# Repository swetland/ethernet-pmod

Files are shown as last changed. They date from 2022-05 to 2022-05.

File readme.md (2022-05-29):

# Ethernet PMOD v2

This PCB is a PMOD (FPGA development board peripheral module) for the
Microchip LAN8720A PHY, to enable 10/100M Ethernet connectivity.

It is configured to accept the necessary 50MHz clock from the FPGA, and
exchanges data using the [RMII standard](https://en.wikipedia.org/wiki/Media-independent_interface#RMII).  A secondary header provides access
to the MDIO/MDC lines to allow access to the management interface.

I have manufactured 10 of these using JLCPCB's PCB fabrication and assembly
service (manually soldering the two throw-hole components myself) and have
used this PMOD successfully with Litex / LiteETH / VexRiscv on a Muse Lab
iCE Sugar Pro FPGA board.

This project is licensed under the [CERN OHL P v2](CERN-OHL-P-v2.txt) Permissive Open Hardware License.

## Design Files and Resources

Original design files are here: [kicad/](kicad/)

Schematic in PDF format here: [export/ethernet-pmod-v2-schematic.pdf](export/ethernet-pmod-v2-schematic.pdf)

Gerbers and CSV files used for a successful JLCPCB order, under [export/jlcpcb/](export/jlcpcb/)

Documentation on the Microchip LAN8720A: https://www.microchip.com/en-us/product/LAN8720A

## Pictures

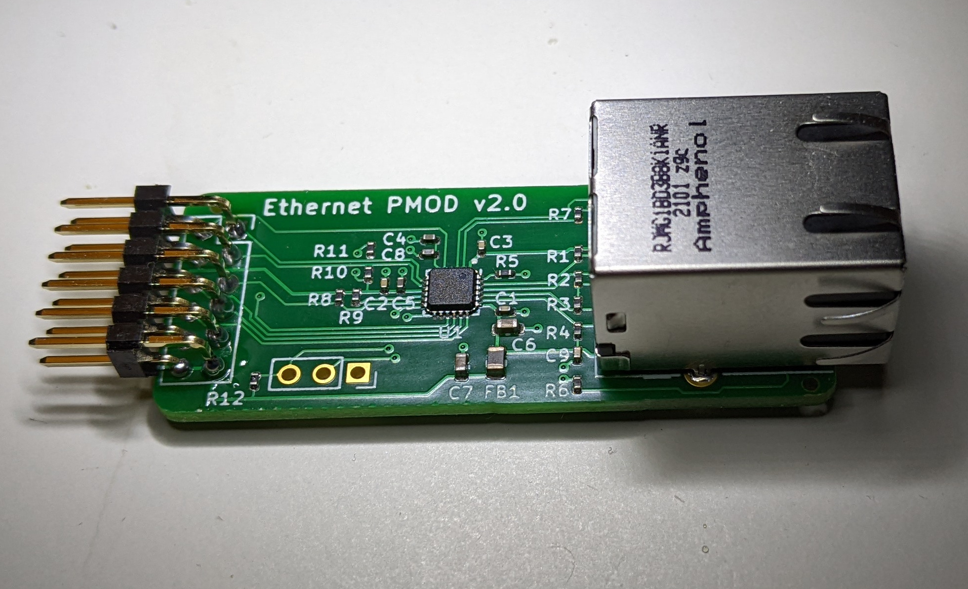
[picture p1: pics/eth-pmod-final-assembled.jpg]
final assembled pmod


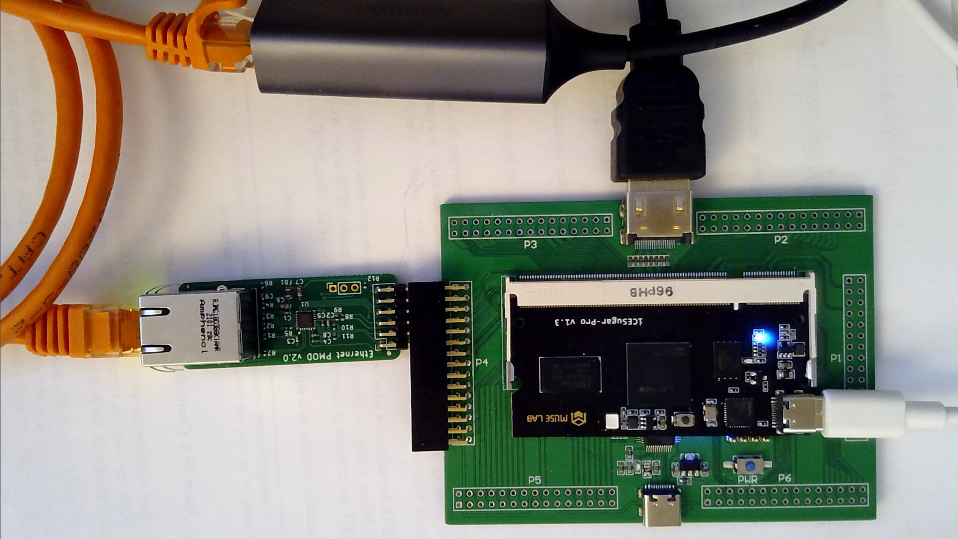
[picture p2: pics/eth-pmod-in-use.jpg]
pmod in use


## PMOD Connector Layout

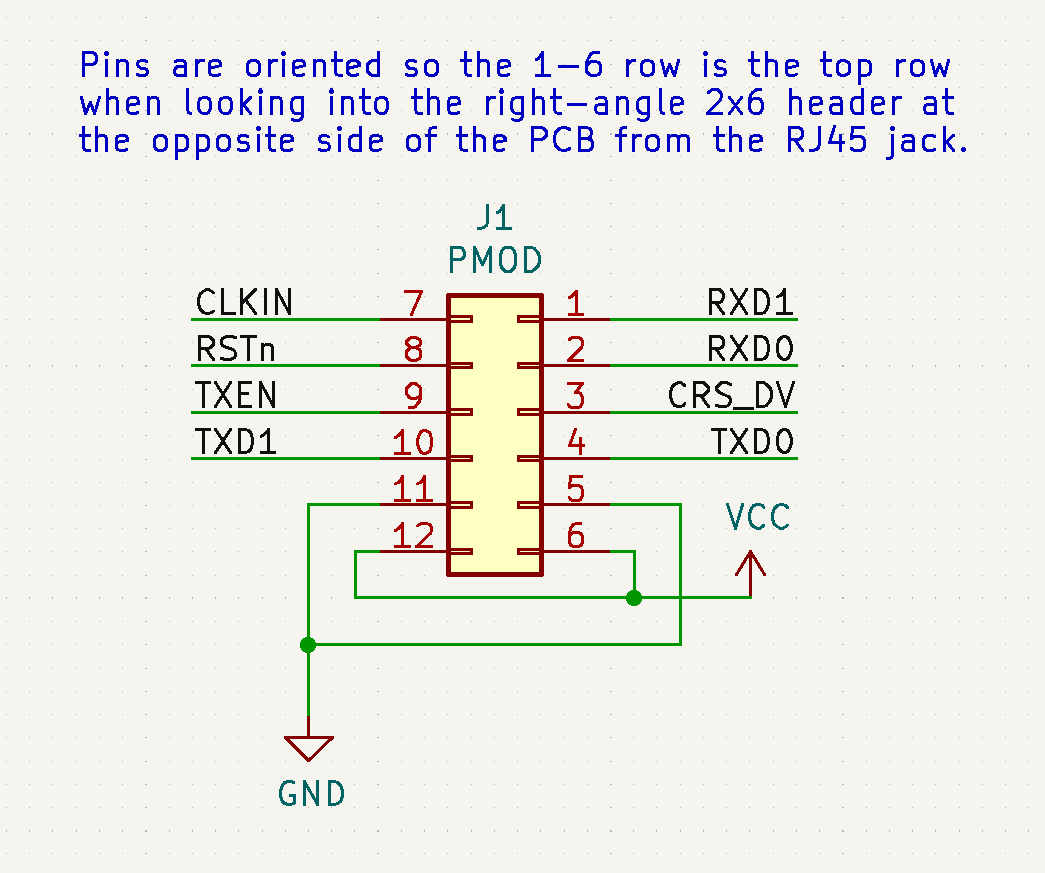
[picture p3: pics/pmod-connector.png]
pmod connector


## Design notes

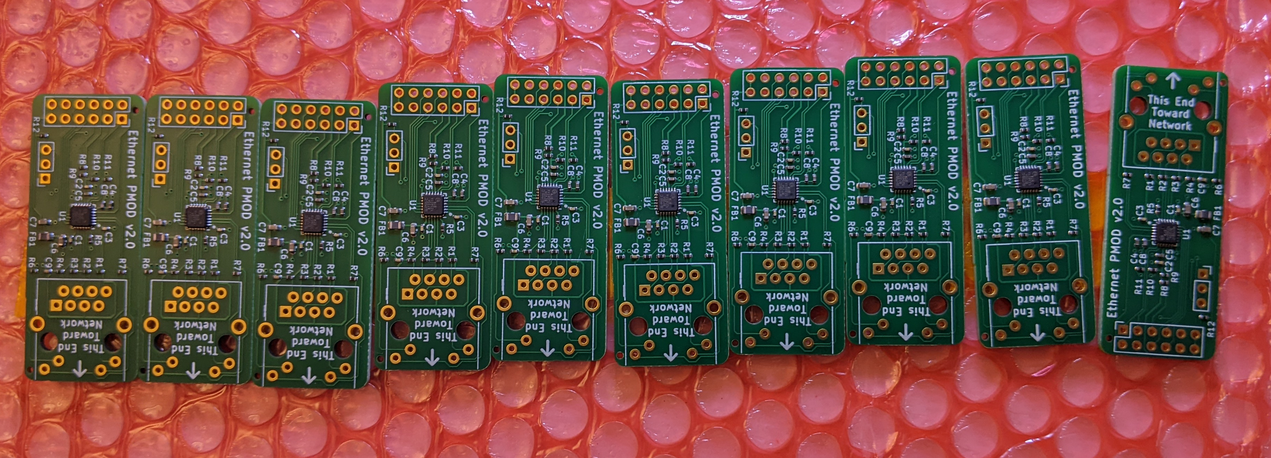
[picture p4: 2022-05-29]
pics/eth-pmod-back-from-fab.jpg

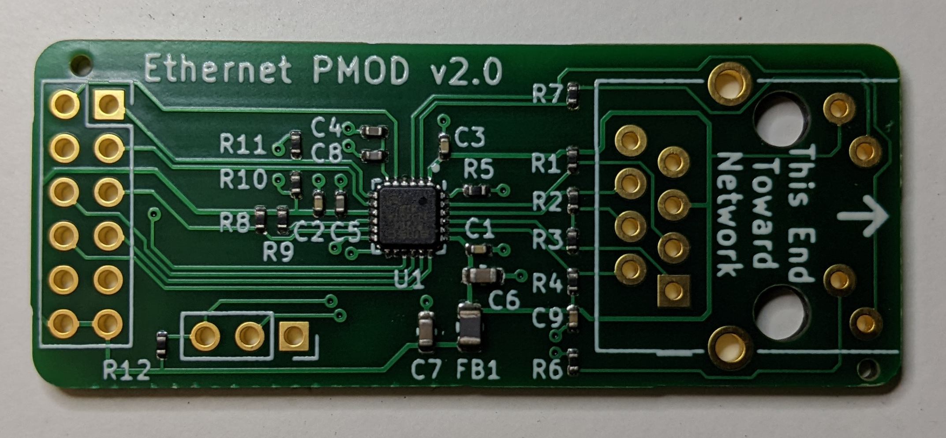
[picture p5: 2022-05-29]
pics/eth-pmod-final-pcb.jpg

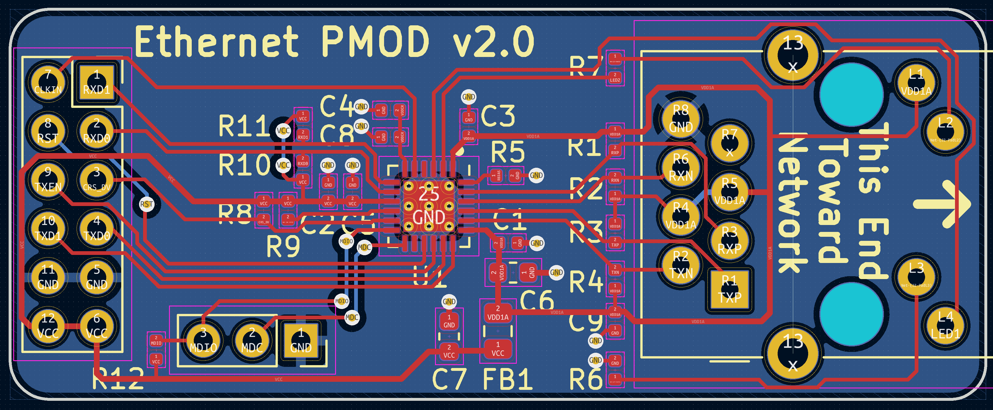
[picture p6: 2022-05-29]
export/ethernet-pmod-v2-layout.jpg

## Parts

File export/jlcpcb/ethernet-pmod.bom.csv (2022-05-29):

Comment | Designator | Footprint | JLCPCB Part #
0.01uF | C1,C2,C3 | 0402_C | C15195
1uF | C4,C5 | 0402_C | C52923
1uF | C6,C7 | 0603_C | C15849
470pF | C8 | 0402_C | C1537
0.022uF | C9 | 0402_C | C1532
FerriteBead | FB1 | 0805_I | C1015
49.9 | R1,R2,R3,R4 | 0402_R | C25120
12.1K | R5 | 0402_R | C25852
270 | R6,R7 | 0402_R | C25099
10K | R8,R9,R10,R11 | 0402_R | C25744
1.5K | R12 | 0402_R | C25867
LAN8720A | U1 | VQFN-24 | C45223

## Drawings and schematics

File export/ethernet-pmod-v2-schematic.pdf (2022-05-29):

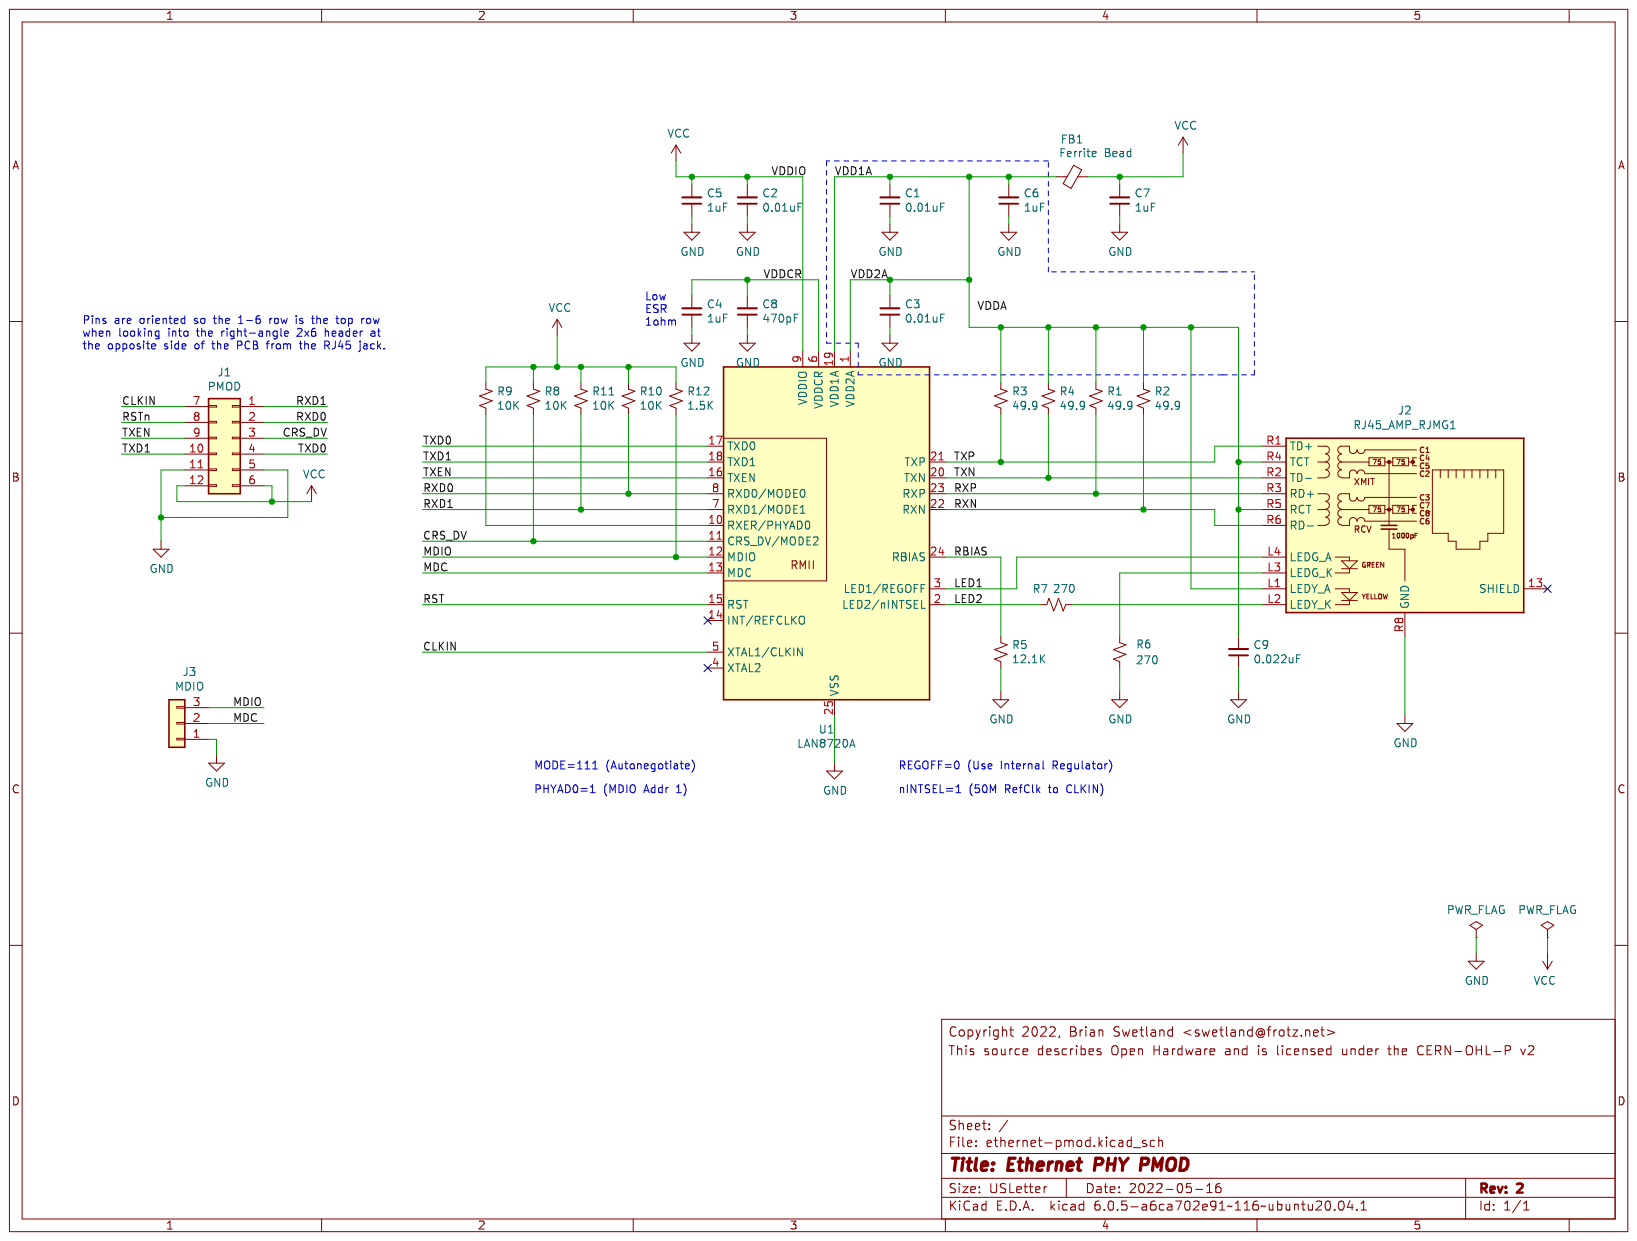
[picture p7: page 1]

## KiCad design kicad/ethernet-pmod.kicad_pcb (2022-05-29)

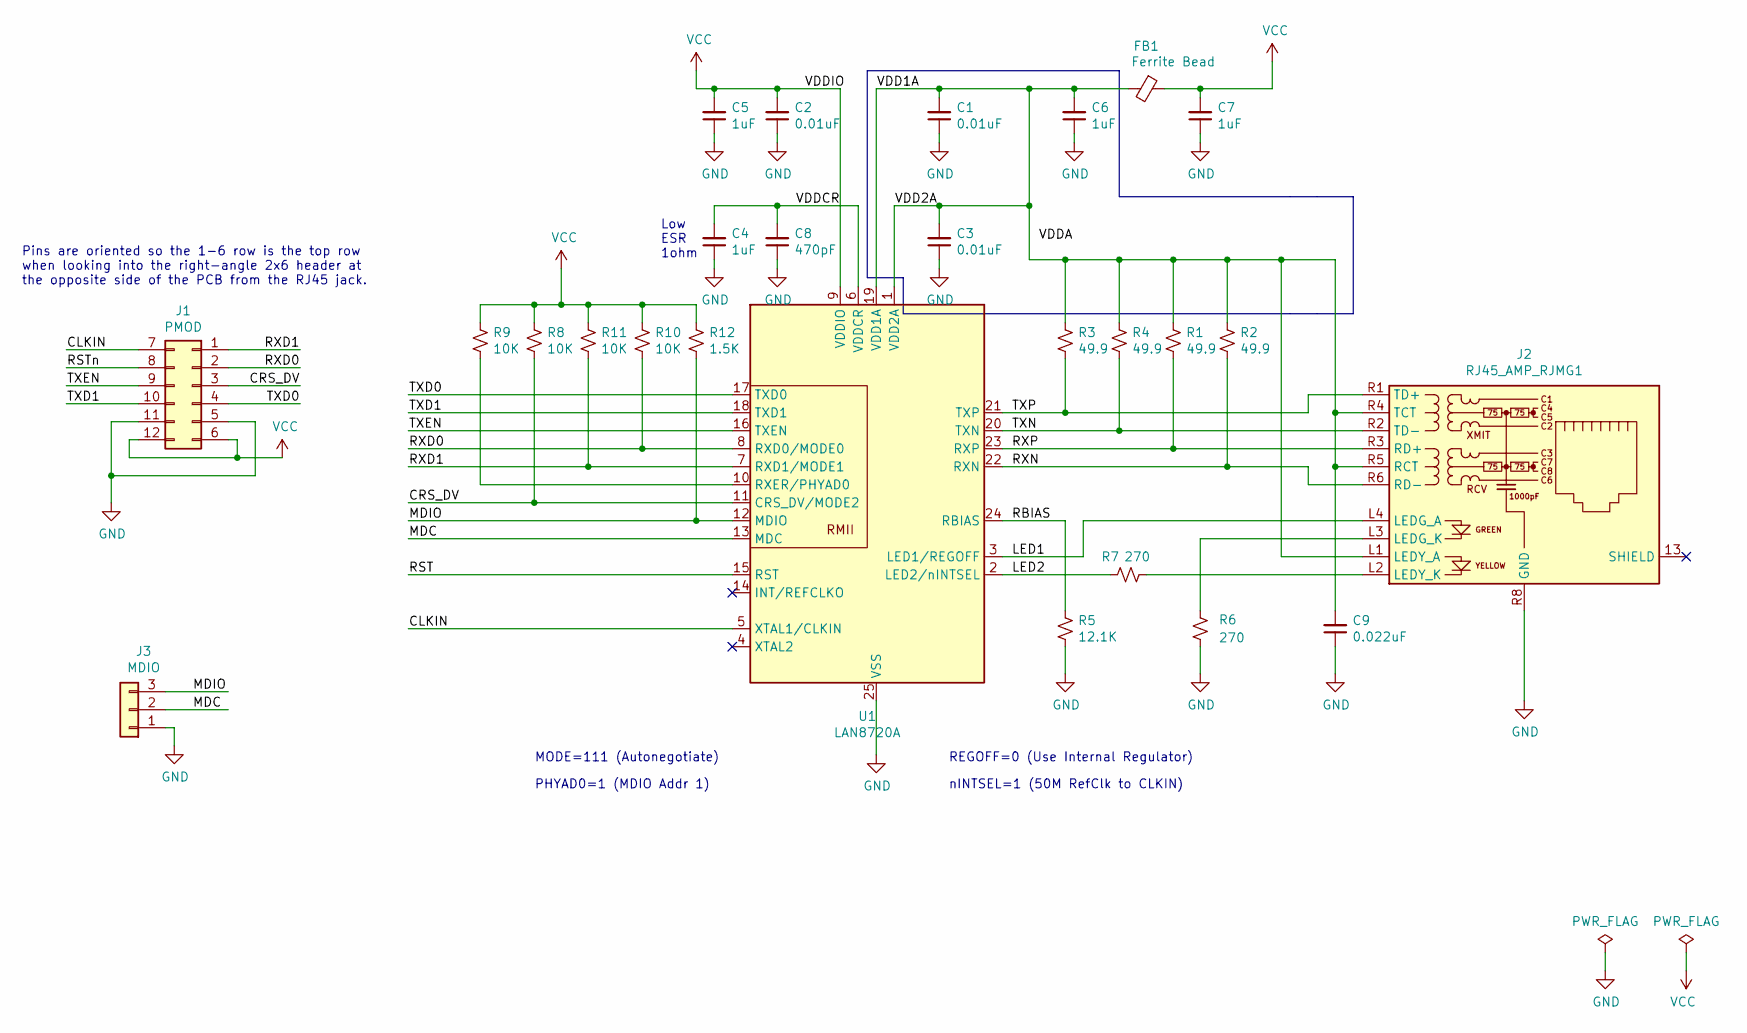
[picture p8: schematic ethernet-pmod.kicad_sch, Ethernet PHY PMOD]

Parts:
C1, C2, C3: 0.01uF; C_0402_1005Metric
C4, C5: 1uF; C_0402_1005Metric
C6, C7: 1uF; C_0603_1608Metric
C8: 470pF; C_0402_1005Metric
C9: 0.022uF; C_0402_1005Metric
FB1: Ferrite Bead; L_0805_2012Metric
J1: PMOD; PMOD_Peripheral_Conn_2x06_P2.54mm_Vertical
J2: RJ45_AMP_RJMG1; RJ45_Amphenol_RJMG1BD3B8K1ANR
J3: MDIO; PinSocket_1x03_P2.54mm_Vertical
R1, R2, R3, R4: 49.9; R_0402_1005Metric
R5: 12.1K; R_0402_1005Metric
R6, R7: 270; R_0402_1005Metric
R8, R9, R10, R11: 10K; R_0402_1005Metric
R12: 1.5K; R_0402_1005Metric
U1: LAN8720A; QFN-24-1EP_4x4mm_P0.5mm_EP2.6x2.6mm_ThermalVias

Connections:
/CLKIN: J1.7, U1.5 (XTAL1/CLKIN)
/CRS_DV: J1.3, R8.2, U1.11 (CRS_DV/MODE2)
/LED1: J2.L4 (LEDG_A), U1.3 (LED1/REGOFF)
/LED2: R7.2, U1.2 (LED2/nINTSEL)
/MDC: J3.2, U1.13 (MDC)
/MDIO: J3.3, R12.2, U1.12 (MDIO)
/RBIAS: R5.1, U1.24 (RBIAS)
/RST: U1.15 (RST)
/RSTn: J1.8
/RXD0: J1.2, R10.2, U1.8 (RXD0/MODE0)
/RXD1: J1.1, R11.2, U1.7 (RXD1/MODE1)
/RXN: J2.R6 (RD-), R2.2, U1.22 (RXN)
/RXP: J2.R3 (RD+), R1.2, U1.23 (RXP)
/TXD0: J1.4, U1.17 (TXD0)
/TXD1: J1.10, U1.18 (TXD1)
/TXEN: J1.9, U1.16 (TXEN)
/TXN: J2.R2 (TD-), R4.2, U1.20 (TXN)
/TXP: J2.R1 (TD+), R3.2, U1.21 (TXP)
/VDD1A: C1.2, C3.2, C6.2, C9.2, FB1.2, J2.L1 (LEDY_A), J2.R4 (TCT), J2.R5 (RCT), R1.1, R2.1, R3.1, R4.1, U1.1 (VDD2A), U1.19 (VDD1A)
/VDDCR: C4.2, C8.2, U1.6 (VDDCR)
GND: C1.1, C2.1, C3.1, C4.1, C5.1, C6.1, C7.1, C8.1, C9.1, J1.5, J1.11, J2.R8 (GND), J3.1, R5.2, R6.2, U1.25 (VSS)
unnamed: J2.L2 (LEDY_K), R7.1
unnamed: J2.L3 (LEDG_K), R6.1
unnamed: R9.2, U1.10 (RXER/PHYAD0)
VCC: C2.2, C5.2, C7.2, FB1.1, J1.6, J1.12, R8.1, R9.1, R10.1, R11.1, R12.1, U1.9 (VDDIO)

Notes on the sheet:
REGOFF=0 (Use Internal Regulator)
nINTSEL=1 (50M RefClk to CLKIN)
Low ESR 1ohm
PHYAD0=1 (MDIO Addr 1)
Pins are oriented so the 1-6 row is the top row when looking into the right-angle 2x6 header at the opposite side of the PCB from the RJ45 jack.
MODE=111 (Autonegotiate)

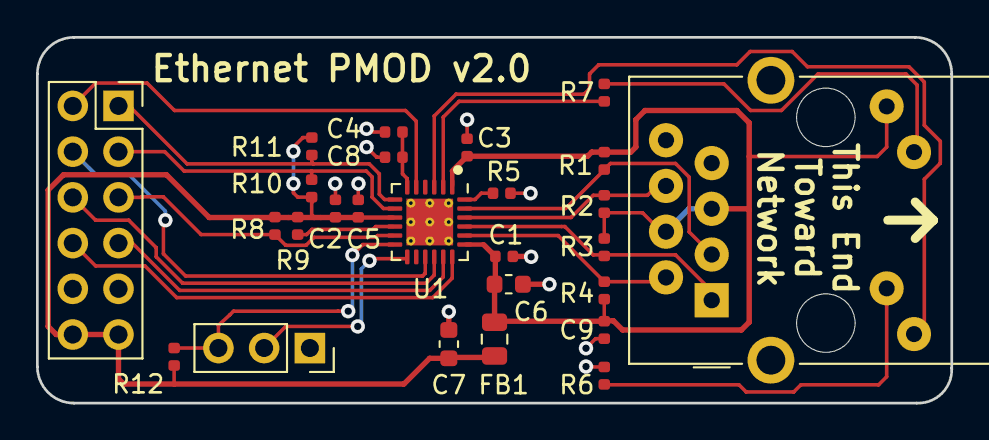
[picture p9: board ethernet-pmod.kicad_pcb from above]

Board: 2 copper layers, 50.8 x 20.3 mm, 26 parts (0 on the bottom side), 23 nets.

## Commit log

2022-05-29 cleanup: improve PMOD header (J1) presentation in schematic
    - tidied up schematic
    - added commentary on pin orientation
    - renamed RST to RSTn for clarity
    - re-exported schematic to PDF
    [ethernet-pmod.kicad_pcb, ethernet-pmod.kicad_sch]
2022-05-29 docs: add picture of pmod connector pinout

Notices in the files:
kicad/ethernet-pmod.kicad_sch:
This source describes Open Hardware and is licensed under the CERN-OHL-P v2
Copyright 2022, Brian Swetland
